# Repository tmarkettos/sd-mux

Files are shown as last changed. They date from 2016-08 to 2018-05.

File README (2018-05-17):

sd-mux stands for Secure Digital Multiplexer.

This is SD card switcher (multiplexer) designed to help automatic testing.

This project is sd-mux controller - binary for controlling sd-mux device.

Requirements:
  1. libftdi1 1.2 - development library
  2. popt - development library
  3. cmake - binary tool

Build:
 - enter into project directory
 - create 'build' directory
 - enter into "build" directory
 - run 'cmake ..'
 - run 'make'

Install:
 - enter into 'build' directory
 - run 'sudo make install' to install binary into '/usr/local/bin' (the default one) directory

Note:
If you want to install files into different directory then add argument to cmake command:
 cmake -DCMAKE_INSTALL_PREFIX=/usr ..
Then again run:
 make
 make install

# Upstream

This is a fork of the git repo from https://git.tizen.org/cgit/tools/testlab/sd-mux/
which is described here: https://wiki.tizen.org/SD_MUX

# Modifications

This version has hardware modified by A. Theodore Markettos to:

* Replace the Micro SD socket with a full-size SD card socket, since we need to use a specific SD card with our FPGA. The downstream adapter boards are still Micro SD format, since we can use adaptors to turn Micro SD into SD when needed.
* Refactor some of the components displaced by the SD card socket.
* Rework the relay section so it provides better isolation for mains power, in particular segregating potentially high and low voltage signals. The pin headers have been removed, and wiring rearranged so that 'live' and 'neutral' are not on adjacent pins on the connectors.
* Add fiducials for automated pick and place
* Replace the 8 way headers to the MicroSD adapters with 10 ways, using more common ribbon cables.  Rotate so right-angle connectors can be used.
* Add spare GPIOs on a header, to match relay boards (eg ebay '4 Channel 5V Relay Module Arduino' with header with GND, 4x GPIOs, 5V)
* Current target is DirtyPCBs.com 2-layer process: 0.8mm ENIG for the usd-adaptor, 1.6mm for the main board.

The software interface is unchanged.

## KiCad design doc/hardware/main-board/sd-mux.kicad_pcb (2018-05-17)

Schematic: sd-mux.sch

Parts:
C1, C2, C4, C5: 27p; C_0805_HandSoldering
C3, C6, C7, C8: 100n; C_0805_HandSoldering
C9: 4.7u; C_0805_HandSoldering
D1, D2: ES1AL; do219ab
FB1: MI0805K400R-10; R_0805_HandSoldering
FID1, FID2, FID3, FID4: Fiducial; Fiducial_1mm_Dia_2.54mm_Outer_CopperTop
J1: 693063020911; mfrn# 693063020911
P1: USB_OTG; conn_usb_B_micro
P2: 629105136821; conn_usb_B_micro
P3, P4: 61400416021; conn_usb_A
P5, P6: Conn_02x05_Odd_Even; IDC-Header_2x05_P2.54mm_Vertical
P7, P10: MKDS 1,5/3; cons_1,5x3
P8: CONN_01X07; PinHeader_1x07_P2.54mm_Vertical
Q1, Q2, Q3, Q4, Q7, Q8: IRF7606PBF; msoic-8
Q5, Q6: 2N7002; SOT-23
R1, R2, R3, R4: 4.7K; R_0805_HandSoldering
R5, R6, R7, R8, R9, R10, R11: 10K; R_0805_HandSoldering
RL1: G2RK-2
U1: TS3USB30EDGSR; msoic-10
U2: FT245RL; ssop-28
U3, U5: 74AHC1G14; SOT-23-5
U4: TS3A27518E; tssop-24

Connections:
/CLK: J1.5 (CLK), U4.7 (COM3)
/CLK_DUT: P5.5, U4.23 (NC3)
/CLK_TS: P6.5, U4.15 (NO3)
/CMD: J1.2 (CMD/MOSI), U4.9 (COM4)
/CMD_DUT: P5.3, U4.21 (NC4)
/CMD_TS: P6.3, U4.17 (NO4)
/DAT0: J1.7 (DAT0/MISO), U4.6 (COM2)
/DAT0_DUT: P5.7, U4.1 (NC2)
/DAT0_TS: P6.7, U4.13 (NO2)
/DAT1: J1.8 (DAT1), U4.4 (COM1)
/DAT1_DUT: P5.8, U4.2 (NC1)
/DAT1_TS: P6.8, U4.11 (NO1)
/DAT2: J1.9 (DAT2), U4.12 (COM6)
/DAT2_DUT: P5.1, U4.22 (NC6)
/DAT2_TS: P6.1, U4.16 (NO6)
/DAT3: J1.1 (CD/DAT3/CS), U4.10 (COM5)
/DAT3_DUT: P5.2, U4.19 (NC5)
/DAT3_TS: P6.2, U4.18 (NO5)
/E: P7.1, P10.1
/GP0: P8.2, U2.5 (D1)
/GP1: P8.3, U2.9 (D5)
/GP2: P8.4, U2.10 (D6)
/GP3: P8.5, U2.6 (D7)
/Lin: P10.2, RL1.6
/Lout: P10.3, RL1.7
/Nin: P7.2, RL1.5
/Nout: P7.3, RL1.4
/POWER_SW_OFF: Q1.4 (G), R6.2, U2.3 (D2)
/POWER_SW_ON: Q2.4 (G), R7.2, U2.2 (D4)
/SOCKET_SEL: Q5.1 (G), R8.2, U2.1 (D0), U3.2, U4.14 (IN2), U4.24 (IN1)
/USB_SEL: Q7.4 (G), R11.2, U1.1 (S), U2.11 (D3), U5.2
/USD_VDD: J1.4 (VDD), Q3.5 (D), Q3.6 (D), Q3.7 (D), Q3.8 (D), Q4.5 (D), Q4.6 (D), Q4.7 (D), Q4.8 (D)
/VDD_DUT: P5.4, Q4.1 (S), Q4.2 (S), Q4.3 (S), R10.1
/VDD_TS: P6.4, Q3.1 (S), Q3.2 (S), Q3.3 (S), R9.1
GND: C1.2, C2.2, C3.2, C4.2, C5.2, C6.2, C7.2, C8.2, C9.2, D1.2 (A), D2.2 (A), J1.3 (GND), J1.6 (GND), J1.GND1, J1.GND2, J1.GND3, J1.GND4, P1.5 (GND), P2.5 (GND), P3.4 (GND), P4.4 (GND), P5.6, P5.9, P5.10, P6.6, P6.9, P6.10, P8.1, Q5.3 (S), Q6.3 (S), R1.2, R2.2, R3.2, R4.2, RL1.9, RL1.10, U1.5 (GND), U1.9 (EN), U2.7 (GND), U2.18 (GND), U2.21 (GND), U2.25 (AGND), U2.26 (TEST), U3.3 (GND), U4.5 (GND), U4.20 (EN), U5.3 (GND)
unnamed: C1.1, P1.6 (shield), R1.1
unnamed: C2.1, P2.6 (shield), R2.1
unnamed: C4.1, P3.5 (shield), R3.1
unnamed: C5.1, P4.5 (shield), R4.1
unnamed: D1.1 (K), Q1.5 (D), Q1.6 (D), Q1.7 (D), Q1.8 (D), RL1.2
unnamed: D2.1 (K), Q2.5 (D), Q2.6 (D), Q2.7 (D), Q2.8 (D), RL1.1
unnamed: FB1.2, P1.1 (VBUS)
unnamed: P1.2 (D-), U2.16 (USBDM)
unnamed: P1.3 (D+), U2.15 (USBDP)
unnamed: P2.1 (VBUS), Q7.1 (S), Q7.2 (S), Q7.3 (S), Q8.1 (S), Q8.2 (S), Q8.3 (S), U5.5 (VCC)
unnamed: P2.2 (D-), U1.6 (D-)
unnamed: P2.3 (D+), U1.4 (D+)
unnamed: P3.1 (VBUS), Q7.5 (D), Q7.6 (D), Q7.7 (D), Q7.8 (D)
unnamed: P3.2 (D-), U1.8 (D1-)
unnamed: P3.3 (D+), U1.2 (D1+)
unnamed: P4.1 (VBUS), Q8.5 (D), Q8.6 (D), Q8.7 (D), Q8.8 (D)
unnamed: P4.2 (D-), U1.7 (D2-)
unnamed: P4.3 (D+), U1.3 (D2+)
unnamed: Q3.4 (G), Q5.2 (D), R9.2
unnamed: Q4.4 (G), Q6.2 (D), R10.2
unnamed: Q6.1 (G), U3.4
unnamed: Q8.4 (G), U5.4
unnamed: R5.2, U2.12 (PWREN#)
VDD: C8.1, C9.1, FB1.1, P8.6, Q1.1 (S), Q1.2 (S), Q1.3 (S), Q2.1 (S), Q2.2 (S), Q2.3 (S), R5.1, R6.1, R7.1, R11.1, U1.10 (VCC), U2.4 (VCCIO), U2.20 (VCC)

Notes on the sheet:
0 - DUT, 1 - TS
SD card socket
Switched MicroUSB host
Switched USB device DUT
Switched USB device TS
SD card output DUT
SD card output TS
MicroUSB host control port
GPIO

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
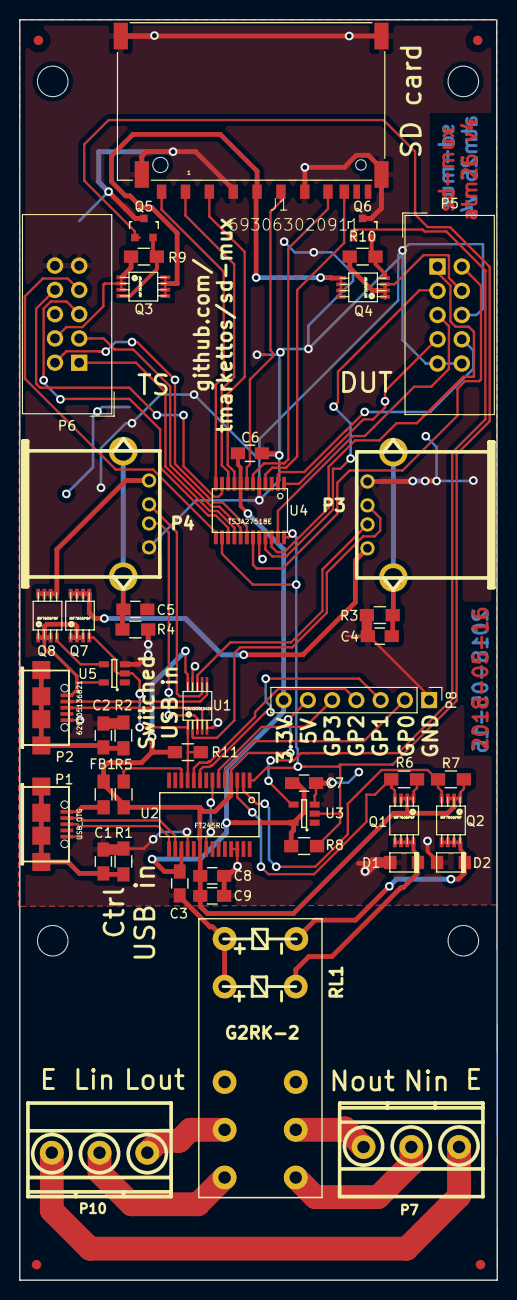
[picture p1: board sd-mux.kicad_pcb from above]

Board: 2 copper layers, 50.0 x 132.0 mm, 51 parts (0 on the bottom side), 60 nets.

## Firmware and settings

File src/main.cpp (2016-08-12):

/*
 *  Copyright (c) 2016 Samsung Electronics Co., Ltd All Rights Reserved
 *
 *  Licensed under the Apache License, Version 2.0 (the "License");
 *  you may not use this file except in compliance with the License.
 *  You may obtain a copy of the License at
 *
 *      http://www.apache.org/licenses/LICENSE-2.0
 *
 *  Unless required by applicable law or agreed to in writing, software
 *  distributed under the License is distributed on an "AS IS" BASIS,
 *  WITHOUT WARRANTIES OR CONDITIONS OF ANY KIND, either express or implied.
 *  See the License for the specific language governing permissions and
 *  limitations under the License
 */
/**
 * @file        src/main.cpp
 * @author      Adam Malinowski <a.malinowsk2@partner.samsung.com>
 * @brief       Main sd-mux-ctrl file
 */

#include <popt.h>
#include <stdio.h>
#include <stdlib.h>
#include <string.h>
#include <unistd.h>

#include <libftdi1/ftdi.h>

#define PRODUCT 0x6001
#define SAMSUNG_VENDOR 0x04e8

#define SOCKET_SEL      (0x01 << 0x00)
#define USB_SEL         (0x01 << 0x03)
#define POWER_SW_OFF    (0x01 << 0x02)
#define POWER_SW_ON     (0x01 << 0x04)
#define DYPER1          (0x01 << 0x05)
#define DYPER2          (0x01 << 0x06)

#define DELAY_100MS     100000

enum CCCommand {
    CCC_List,
    CCC_DUT,
    CCC_TS,
    CCC_Tick,
    CCC_Pins,
    CCC_Info,
    CCC_ShowSerial,
    CCC_SetSerial,
    CCC_Init,
    CCC_Status,
    CCC_DyPer1,
    CCC_DyPer2,
    CCC_None
};

enum Target {
    T_DUT,
    T_TS
};

enum CCOption {
    CCO_DeviceId,
    CCO_DeviceSerial,
    CCO_TickTime,
    CCO_BitsInvert,
    CCO_Vendor,
    CCO_DyPer,
    CCO_MAX
};

union CCOptionValue {
    int argn;
    char *args;
};

int doPower(bool off, bool on, CCOptionValue options[]);
int selectTarget(Target target, CCOptionValue options[]);

int listDevices(CCOptionValue options[]) {
    int fret, i;
    struct ftdi_context *ftdi;
    struct ftdi_device_list *devlist, *curdev;
#define STRING_SIZE 128
    char manufacturer[STRING_SIZE + 1], description[STRING_SIZE + 1], serial[STRING_SIZE + 1];
    int retval = EXIT_SUCCESS;

    if ((ftdi = ftdi_new()) == 0) {
        fprintf(stderr, "ftdi_new failed\n");
        return EXIT_FAILURE;
    }

    if ((fret = ftdi_usb_find_all(ftdi, &devlist, options[CCO_Vendor].argn, PRODUCT)) < 0) {
        fprintf(stderr, "ftdi_usb_find_all failed: %d (%s)\n", fret, ftdi_get_error_string(ftdi));
        ftdi_free(ftdi);
        return EXIT_FAILURE;
    }

    if (options[CCO_DeviceId].argn == -1) {
        printf("Number of FTDI devices found: %d\n", fret);
    }

    i = 0;
    for (curdev = devlist; curdev != NULL; i++) {
        if (options[CCO_DeviceId].argn == -1 || options[CCO_DeviceId].argn == i) {
            if ((fret = ftdi_usb_get_strings(ftdi, curdev->dev, manufacturer, STRING_SIZE, description, STRING_SIZE,
                    serial, STRING_SIZE)) < 0) {
                fprintf(stderr, "ftdi_usb_get_strings failed: %d (%s)\n", fret, ftdi_get_error_string(ftdi));
                retval = EXIT_FAILURE;
                goto finish_him;
            }
            if (options[CCO_DeviceId].argn == -1) {
                printf("Dev: %d, Manufacturer: %s, Serial: %s, Description: %s\n", i,
                       manufacturer, serial, description);
            } else {
                printf("%s", serial);
            }
        }
        curdev = curdev->next;
    }

finish_him:
    ftdi_list_free(&devlist);
    ftdi_free(ftdi);

    return retval;
}

struct ftdi_context* openDevice(CCOptionValue options[]) {
    struct ftdi_context *ftdi = NULL;
    int fret;

    if ((options[CCO_DeviceSerial].args == NULL) && (options[CCO_DeviceId].argn < 0)) {
        fprintf(stderr, "No serial number or device id provided!\n");
        return NULL;
    }

    if ((ftdi = ftdi_new()) == 0) {
        fprintf(stderr, "ftdi_new failed\n");
        return NULL;
    }

    if (options[CCO_DeviceSerial].args != NULL) {
        fret = ftdi_usb_open_desc_index(ftdi, options[CCO_Vendor].argn, PRODUCT, NULL, options[CCO_DeviceSerial].args, 0);
    } else {
        fret = ftdi_usb_open_desc_index(ftdi, options[CCO_Vendor].argn, PRODUCT, NULL, NULL, options[CCO_DeviceId].argn);
    }
    if (fret < 0) {
        fprintf(stderr, "Unable to open ftdi device: %d (%s)\n", fret, ftdi_get_error_string(ftdi));
        ftdi_free(ftdi);
        return NULL;
    }

    return ftdi;
}

int showInfo(CCOptionValue options[]) {
    struct ftdi_context *ftdi;
    int fret, ret = EXIT_SUCCESS;

    ftdi = openDevice(options);
    if (ftdi == NULL) {
        return EXIT_FAILURE;
    }

    fret = ftdi_read_eeprom(ftdi);
    if (fret < 0) {
        fprintf(stderr, "Unable to read ftdi eeprom: %d (%s)\n", fret, ftdi_get_error_string(ftdi));
        ret = EXIT_FAILURE;
        goto finish_him;
    }

    fret = ftdi_eeprom_decode(ftdi, 1);
    if (fret < 0) {
        fprintf(stderr, "Unable to decode ftdi eeprom: %d (%s)\n", fret, ftdi_get_error_string(ftdi));
        ret = EXIT_FAILURE;
        goto finish_him;
    }

finish_him:
    ftdi_usb_close(ftdi);
    ftdi_free(ftdi);

    return ret;
}

int doInit(CCOptionValue options[]) {
    if (doPower(true, false, options) != EXIT_SUCCESS) {
        return EXIT_FAILURE;
    }

    if (selectTarget(T_TS, options) != EXIT_SUCCESS) {
        return EXIT_FAILURE;
    }

    return EXIT_SUCCESS;
}

int setSerial(char *serialNumber, CCOptionValue options[]) {
    struct ftdi_context *ftdi;
    int f, ret = EXIT_FAILURE;

    ftdi = openDevice(options);
    if (ftdi == NULL) {
        return EXIT_FAILURE;
    }

    f = ftdi_eeprom_initdefaults(ftdi, (char*)"SRPOL", (char *)"sd-mux", serialNumber);
    if (f < 0) {
        fprintf(stderr, "Unable to set eeprom strings: %d (%s)\n", f, ftdi_get_error_string(ftdi));
        goto finish_him;
    }

    f = ftdi_set_eeprom_value(ftdi, VENDOR_ID, SAMSUNG_VENDOR);
    if (f < 0) {
        fprintf(stderr, "Unable to set eeprom strings: %d (%s)\n", f, ftdi_get_error_string(ftdi));
        goto finish_him;
    }

    f = ftdi_eeprom_build(ftdi);
    if (f < 0) {
        fprintf(stderr, "Unable to build eeprom: %d (%s)\n", f, ftdi_get_error_string(ftdi));
        goto finish_him;
    }

    f = ftdi_write_eeprom(ftdi);
    if (f < 0) {
        fprintf(stderr, "Unable to write eeprom into device: %d (%s)\n", f, ftdi_get_error_string(ftdi));
        goto finish_him;
    }

    ret = EXIT_SUCCESS;

finish_him:
    ftdi_usb_close(ftdi);
    ftdi_free(ftdi);

    return ret;
}

int writePins(struct ftdi_context *ftdi, unsigned char pins) {
    int f = ftdi_write_data(ftdi, &pins, 1);
    if (f < 0) {
        fprintf(stderr,"write failed for 0x%x, error %d (%s)\n", pins, f, ftdi_get_error_string(ftdi));
        return EXIT_FAILURE;
    }
    return EXIT_SUCCESS;
}

struct ftdi_context* prepareDevice(CCOptionValue options[], unsigned char *pins) {
    struct ftdi_context *ftdi;
    int f;

    ftdi = openDevice(options);
    if (ftdi == NULL) {
        return NULL;
    }

    f = ftdi_set_bitmode(ftdi, 0xFF, BITMODE_BITBANG);
    if (f < 0) {
        fprintf(stderr, "Unable to enable bitbang mode: %d (%s)\n", f, ftdi_get_error_string(ftdi));
        ftdi_usb_close(ftdi);
        ftdi_free(ftdi);
        return NULL;
    }

    if (pins != NULL) {
        f = ftdi_read_data(ftdi, pins, 1);
        if (f < 0) {
            fprintf(stderr,"read failed, error %d (%s)\n", f, ftdi_get_error_string(ftdi));
            ftdi_usb_close(ftdi);
            ftdi_free(ftdi);
            return NULL;
        }
    }

    return ftdi;
}

int powerOff(struct ftdi_context *ftdi, unsigned char *pins) {
    // Turn on the coil
    *pins |= POWER_SW_ON;
    *pins &= ~(POWER_SW_OFF);
    if (writePins(ftdi, *pins) != EXIT_SUCCESS)
        return EXIT_FAILURE;

    // Wait for 100ms
    usleep(DELAY_100MS);

    // Turn off the coil
    *pins |= POWER_SW_OFF;
    if (writePins(ftdi, *pins) != EXIT_SUCCESS)
        return EXIT_FAILURE;

    return EXIT_SUCCESS;
}

int powerOn(struct ftdi_context *ftdi, unsigned char *pins) {
    // Turn on the coil
    *pins |= POWER_SW_OFF;
    *pins &= ~(POWER_SW_ON);
    if (writePins(ftdi, *pins) != EXIT_SUCCESS)
        return EXIT_FAILURE;

    // Wait for 100ms
    usleep(DELAY_100MS);

    // Turn off the coil
    *pins |= POWER_SW_ON;
    if (writePins(ftdi, *pins) != EXIT_SUCCESS)
        return EXIT_FAILURE;

    return EXIT_SUCCESS;
}

int doPower(bool off, bool on, CCOptionValue options[]) {
    unsigned char pins;
    int ret = EXIT_SUCCESS;

    int period = 1000;
    if (options[CCO_TickTime].argn > 0) {
        period = options[CCO_TickTime].argn;
    }

    struct ftdi_context *ftdi = prepareDevice(options, &pins);
    if (ftdi == NULL)
        return EXIT_FAILURE;

    ret = powerOff(ftdi, &pins);
    if (off && (ret != EXIT_SUCCESS)) {
        ret = EXIT_FAILURE;
        goto finish_him;
    }

    // Wait for specified period in ms
    usleep(period * 1000);

    ret = powerOn(ftdi, &pins);
    if (on && (ret != EXIT_SUCCESS)) {
        ret = EXIT_FAILURE;
        goto finish_him;
    }

finish_him:
    ftdi_usb_close(ftdi);
    ftdi_free(ftdi);

    return ret;
}

int selectTarget(Target target, CCOptionValue options[]) {
    unsigned char pins;
    int ret = EXIT_SUCCESS;

    struct ftdi_context *ftdi = prepareDevice(options, &pins);
    if (ftdi == NULL)
        return EXIT_FAILURE;

    if (target == T_DUT) {
        pins &= ~(USB_SEL);
        pins &= ~(SOCKET_SEL);
        if (powerOn(ftdi, &pins) != EXIT_SUCCESS) {  // Also selects USB and SD
            ret = EXIT_FAILURE;
            goto finish_him;
        }
    } else {
        pins |= USB_SEL;
        pins |= SOCKET_SEL;
        if (powerOff(ftdi, &pins) != EXIT_SUCCESS) { // Also selects USB and SD
            ret = EXIT_FAILURE;
            goto finish_him;
        }
    }

finish_him:
    ftdi_usb_close(ftdi);
    ftdi_free(ftdi);

    return ret;
}

int setPins(unsigned char pins, CCOptionValue options[]) {
    struct ftdi_context *ftdi = prepareDevice(options, NULL);
    if (ftdi == NULL)
        return EXIT_FAILURE;

    if (options[CCO_DeviceSerial].args) {
        pins = ~pins;
    }

    printf("Write data: 0x%x\n", pins);

    int ret = writePins(ftdi, pins);

    ftdi_usb_close(ftdi);
    ftdi_free(ftdi);

    return ret;
}

int showStatus(CCOptionValue options[]) {
    unsigned char pins;
    struct ftdi_context *ftdi = prepareDevice(options, &pins);
    if (ftdi == NULL)
        return EXIT_FAILURE;

    ftdi_usb_close(ftdi);
    ftdi_free(ftdi);

    if (!(pins & POWER_SW_ON && pins & POWER_SW_OFF)) {
        fprintf(stdout, "Device not initialized!\n");
        return 0;
    }

    fprintf(stdout, "USB connected to: %s\n", pins & USB_SEL ? "TS" : "DUT");
    fprintf(stdout, "SD connected to: %s\n", pins & SOCKET_SEL ? "TS" : "DUT");

    return 0;
}

int setDyPer(CCCommand cmd, CCOptionValue options[]) {
    unsigned char pins;
    bool switchOn;
    int ret = EXIT_SUCCESS, dyper;

    struct ftdi_context *ftdi = prepareDevice(options, &pins);
    if (ftdi == NULL)
        return EXIT_FAILURE;

    #define STRON "ON"
    #define STROFF "OFF"

    if (strncasecmp(STRON, options[CCO_DyPer].args, strlen(STRON)) == 0) {
      switchOn = true;
    } else if (strncasecmp(STROFF, options[CCO_DyPer].args, strlen(STROFF)) == 0) {
      switchOn = false;
    } else {
      fprintf(stderr,"Invalid DyPer argument! Use \"on\" or \"off\".\n");
      goto finish_him;
    }

    dyper = cmd == CCC_DyPer1 ? DYPER1 : DYPER2;
    pins = switchOn ? pins | dyper : pins & ~dyper;

    if (writePins(ftdi, pins) != EXIT_SUCCESS)
        ret = EXIT_FAILURE;

finish_him:
    ftdi_usb_close(ftdi);
    ftdi_free(ftdi);

    return ret;
}

int parseArguments(int argc, const char **argv, CCCommand *cmd, int *arg, char *args, size_t argsLen,
                   CCOptionValue options[]) {
    char c;
    char *serial = NULL;

    poptContext optCon;
    struct poptOption optionsTable[] = {
            // Commands
            { "list", 'l', POPT_ARG_NONE, NULL, 'l', "lists all sd-mux devices connected to PC", NULL },
            { "info", 'i', POPT_ARG_NONE, NULL, 'i', "displays info about device", "serial number" },
            { "show-serial", 'o', POPT_ARG_NONE, NULL, 'o', "displays serial number of given device", NULL },
            { "set-serial", 'r', POPT_ARG_STRING, &serial, 'r', "writes serial number to given device", NULL },
            { "init", 't', POPT_ARG_NONE, NULL, 't', "initialize target board", NULL },
            { "dut", 'd', POPT_ARG_NONE, NULL, 'd', "connects SD card and USB to the target board", NULL },
            { "ts", 's', POPT_ARG_NONE, NULL, 's', "connects SD card and USB to the test server", NULL },
            { "pins", 'p', POPT_ARG_INT, arg, 'p', "write pin state in bitbang mode", NULL },
            { "tick", 'c', POPT_ARG_NONE, NULL, 'c', "turn off and on power supply of DUT", NULL },
            { "status", 'u', POPT_ARG_NONE, NULL, 'u', "show current status: DUT or TS or NOINIT", NULL },
            { "dyper1", 'y', POPT_ARG_STRING, &options[CCO_DyPer].args, 'y', "Connect or disconnect terminals of 1st dynamic jumper; STRING = \"on\" or \"off\"", NULL },
            { "dyper2", 'z', POPT_ARG_STRING, &options[CCO_DyPer].args, 'z', "Connect or disconnect terminals of 2nd dynamic jumper; STRING = \"on\" or \"off\"", NULL },
            // Options
            { "tick-time", 'm', POPT_ARG_INT, &options[CCO_TickTime].argn, 'm', "set time delay for 'tick' command",
                    NULL },
            { "device-id", 'v', POPT_ARG_INT, &options[CCO_DeviceId].argn, 'v', "use device with given id", NULL },
            { "device-serial", 'e', POPT_ARG_STRING, &options[CCO_DeviceSerial].args, 'e',
                    "use device with given serial number", NULL },
            { "vendor", 'x', POPT_ARG_INT, &options[CCO_Vendor].argn, 'x', "use device with given vendor id", NULL },
            { "invert", 'n', POPT_ARG_NONE, NULL, 'n', "invert bits for --pins command", NULL },
            POPT_AUTOHELP
            { NULL, 0, 0, NULL, 0, NULL, NULL }
    };

    optCon = poptGetContext(NULL, argc, argv, optionsTable, 0);
    poptSetOtherOptionHelp(optCon, "command");
    if (argc < 2) {
        poptPrintUsage(optCon, stderr, 0);
        return EXIT_SUCCESS;
    }
    /* Now do options processing, get portname */
    while ((c = poptGetNextOpt(optCon)) >= 0) {
        switch (c) {
            case 'l':
                *cmd = CCC_List;
                break;
            case 'i':
                *cmd = CCC_Info;
                break;
            case 'o':
                *cmd = CCC_ShowSerial;
                break;
            case 'r':
                *cmd = CCC_SetSerial;
                break;
            case 't':
                *cmd = CCC_Init;
                break;
            case 'd':
                *cmd = CCC_DUT;
                break;
            case 's':
                *cmd = CCC_TS;
                break;
            case 'p':
                *cmd = CCC_Pins;
                break;
            case 'c':
                *cmd = CCC_Tick;
                break;
            case 'u':
                *cmd = CCC_Status;
                break;
            case 'y':
                *cmd = CCC_DyPer1;
                break;
            case 'z':
                *cmd = CCC_DyPer2;
                break;
            case 'n':
                options[CCO_BitsInvert].argn = 1;
                break;
        }
    }

    poptFreeContext(optCon);

    if (serial)
        snprintf(args, argsLen, "%s", serial);
    free(serial);

    if (c < -1) {
        fprintf(stderr, "%s: %s\n", poptBadOption(optCon, POPT_BADOPTION_NOALIAS), poptStrerror(c));
        return EXIT_FAILURE;
    }

    return EXIT_SUCCESS;
}

int main(int argc, const char **argv) {
    CCCommand cmd = CCC_None;
    int arg;
    char args[64];
    CCOptionValue options[CCO_MAX];
    memset(&options, 0, sizeof(options));
    options[CCO_DeviceId].argn = -1;
    options[CCO_Vendor].argn = SAMSUNG_VENDOR;

    if (parseArguments(argc, argv, &cmd, &arg, args, sizeof(args), options) != EXIT_SUCCESS) {
        return EXIT_FAILURE;
    }

    switch (cmd) {
    case CCC_None:
        fprintf(stderr, "No command specified\n");
        return EXIT_FAILURE;
    case CCC_List:
        return listDevices(options);
    case CCC_Info:
        return showInfo(options);
    case CCC_ShowSerial:
        return listDevices(options);
    case CCC_SetSerial:
        return setSerial(args, options);
    case CCC_Init:
        return doInit(options);
    case CCC_DUT:
        return selectTarget(T_DUT, options);
    case CCC_TS:
        return selectTarget(T_TS, options);
    case CCC_Tick:
        return doPower(true, true, options);
    case CCC_Pins:
        return setPins((unsigned char)arg, options);
    case CCC_DyPer1:
    case CCC_DyPer2:
        return setDyPer(cmd, options);
    case CCC_Status:
        return showStatus(options);
    }

    return EXIT_SUCCESS;
}

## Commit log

2017-06-16 Fix power supply connection of USB switch inverter
    Power supply pin of U5 was connected to 3.3V. Q8, driven from this
    inverter, couldn't be fully closed as maximum output voltage from
    the inverter was 3.3V. Now, the inverter, is connected to VCC pin
    of USB connector which gives 5V.
    [sd-mux.kicad_pcb, sd-mux.sch]
2017-07-18 Add fabrication files for main board v 2.1
2017-08-29 Replace Micro SD card with SD card socket. Add fiducials
    [sd-mux.kicad_pcb, sd-mux.sch]
2017-08-29 Make all vias 0.5mm. Re-lay relay tracks for better isolation
    [sd-mux.kicad_pcb]
2017-08-29 Refactor relay section so that it obeys mains isolation. Delete headers, rearrange so that 'live' and 'neutral' sections are separated. Rejig pinout so that unused pins never become live, and rotate 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
    [sd-mux.kicad_pcb, sd-mux.sch]
2017-08-29 Tweak pours to increase clearances. Add some keepouts around ICs where lacking soldermask is likely to be problematic
    [sd-mux.kicad_pcb]
2018-05-17 Fix unrouted tracks
    [sd-mux.kicad_pcb]
2018-05-17 Move 8w headers up so can fit shrouded 10w versions, flip so can use right angled
    [sd-mux.kicad_pcb, sd-mux.sch]
2018-05-17 Fix up missing footprints, replace 8w IDC with 10w on PCB so can use common ribbon cables
    [sd-mux.kicad_pcb, sd-mux.sch]
2018-05-17 Pin out spare GPIOs to a header, eg to match ebay '4 channel relay module Arduino RPi'
    [sd-mux.kicad_pcb, sd-mux.sch]
2018-05-17 Label up inputs and add URL in silk
    [sd-mux.kicad_pcb, sd-mux.sch]
2018-05-17 Move up IDC connector to be symmetrical
    [sd-mux.kicad_pcb]
2018-05-17 Remove origin mark that confuses DirtyPCBs
    [sd-mux.kicad_pcb]
2018-05-17 Respin usd-adapter with silk and soldermask
